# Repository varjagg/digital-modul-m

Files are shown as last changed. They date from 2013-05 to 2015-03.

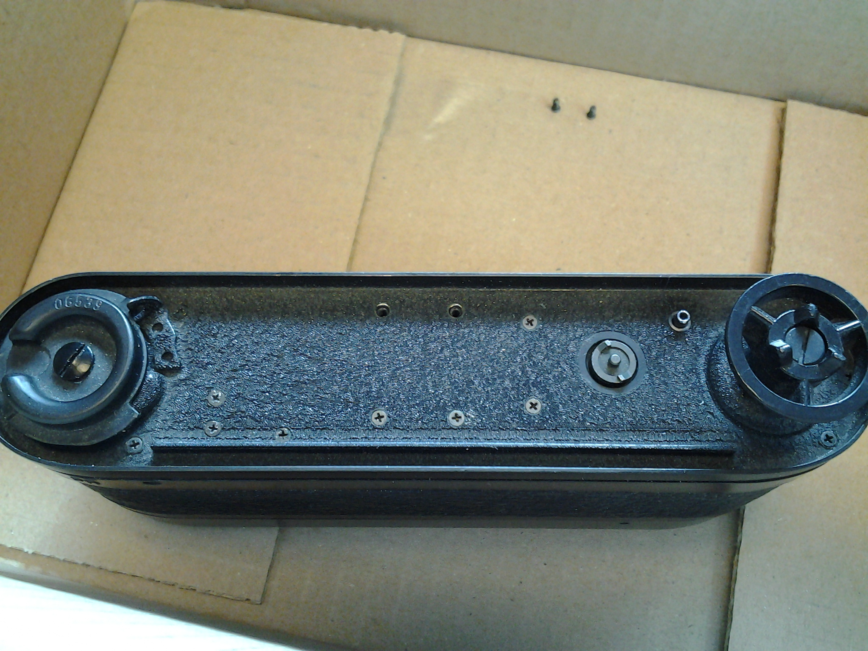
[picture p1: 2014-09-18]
images/assy/2013-04-25 13.17.37.jpg

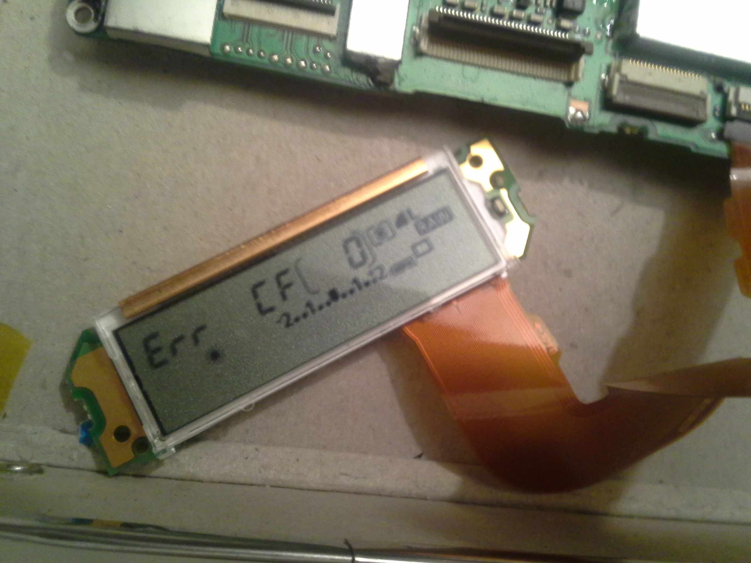
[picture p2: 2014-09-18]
images/assy/2014-04-14 23.03.26.jpg

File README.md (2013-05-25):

Digital Modul M
===============

An Arduino Pro Mini based controller for Canon EOS 350D covnerted into digital back.

Handles shutter release and ISO selection sequence via a 5 position rotary switch.

Handles shutter release from Leica via M Sync (flashbulb) terminal and triggers shutter release on the Canon.

Emulates phantom limbs of the Canon (feedback from shutter and mirror position sensors).

Still work in progress!

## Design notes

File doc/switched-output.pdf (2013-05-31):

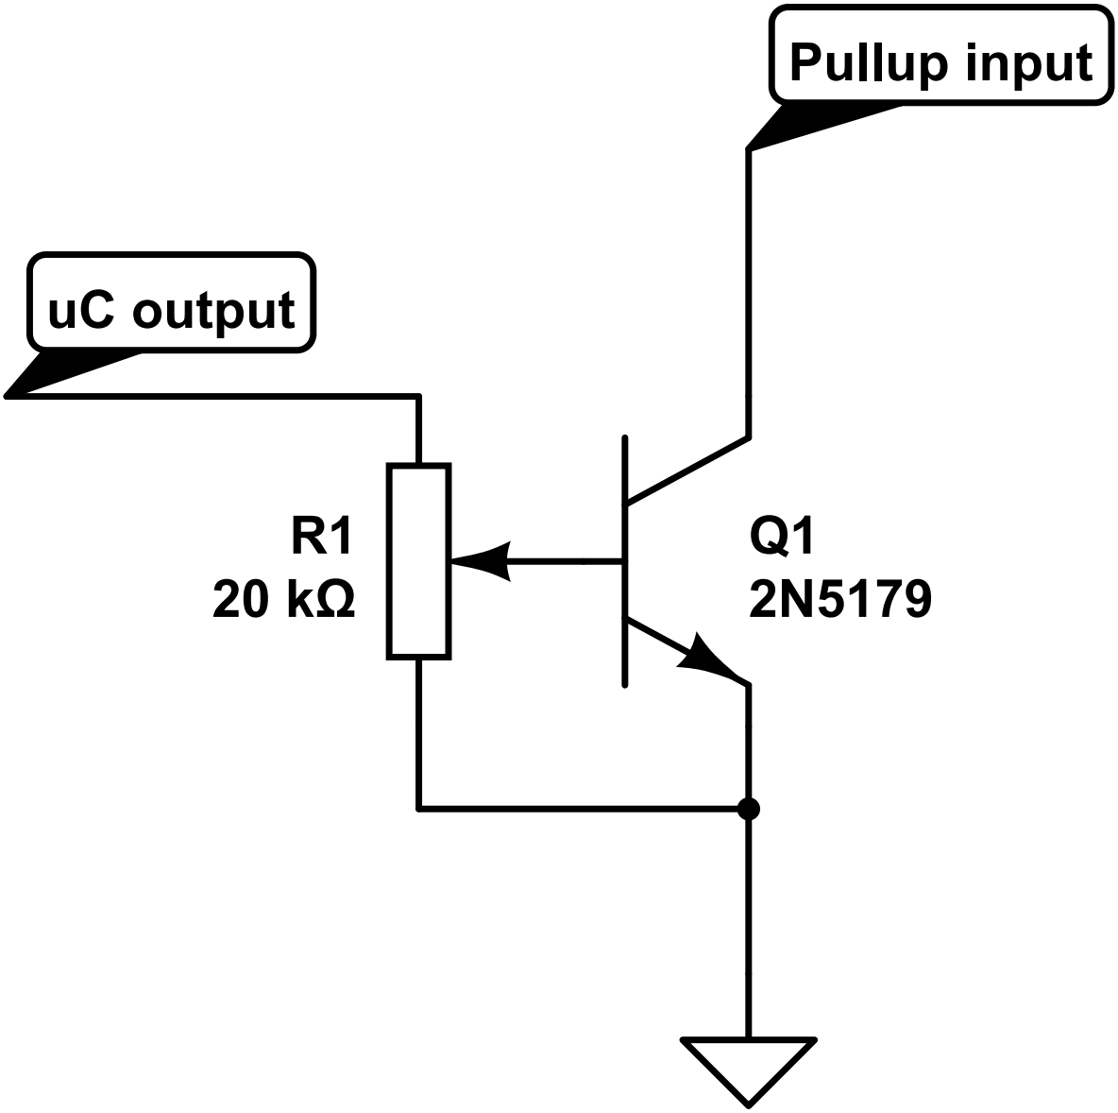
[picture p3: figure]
Pullup input; uC output

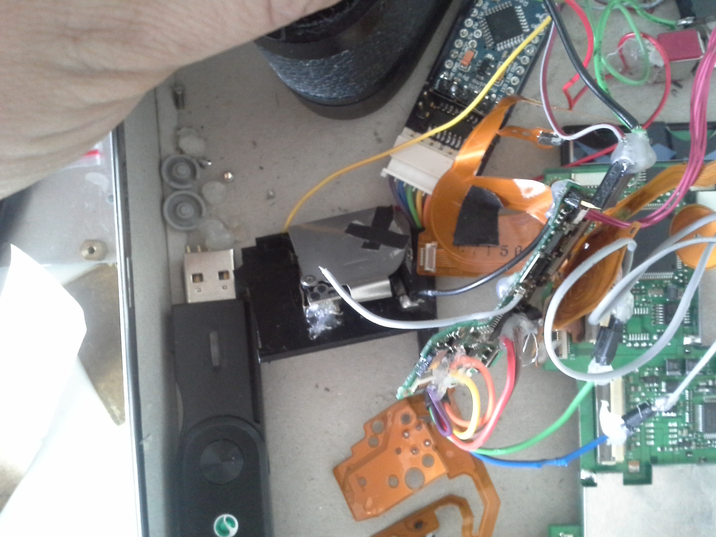
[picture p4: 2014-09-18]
images/assy/2014-08-03 16.27.18.jpg

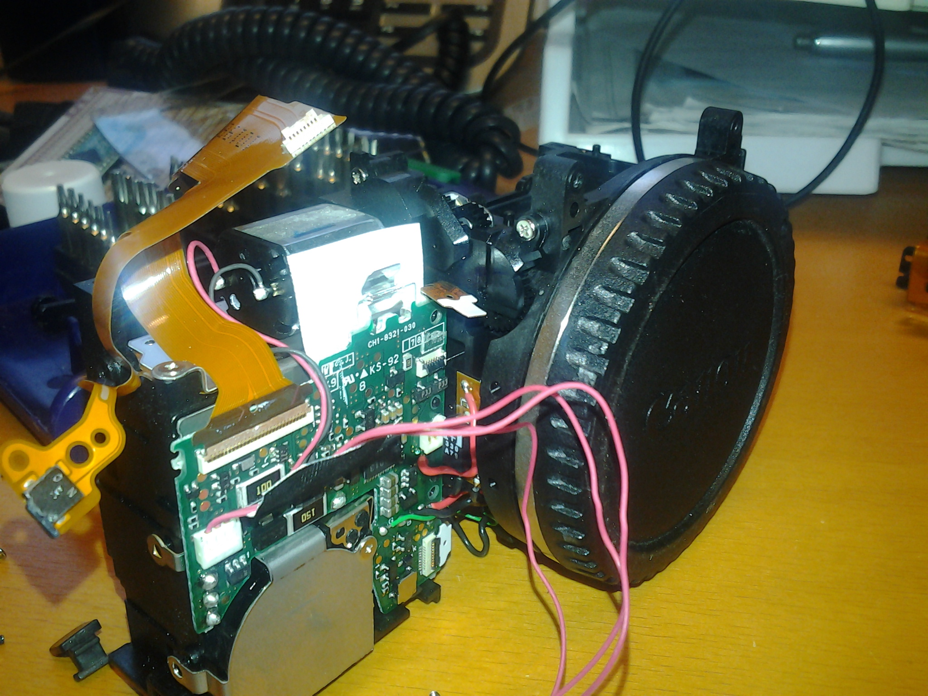
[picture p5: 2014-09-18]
images/assy/2013-05-06 18.22.18.jpg

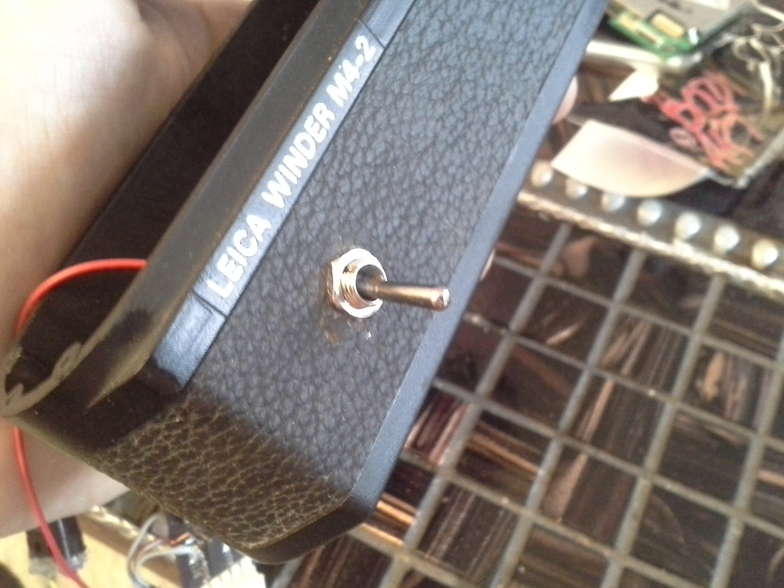
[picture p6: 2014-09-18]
images/assy/2014-08-03 17.57.18.jpg

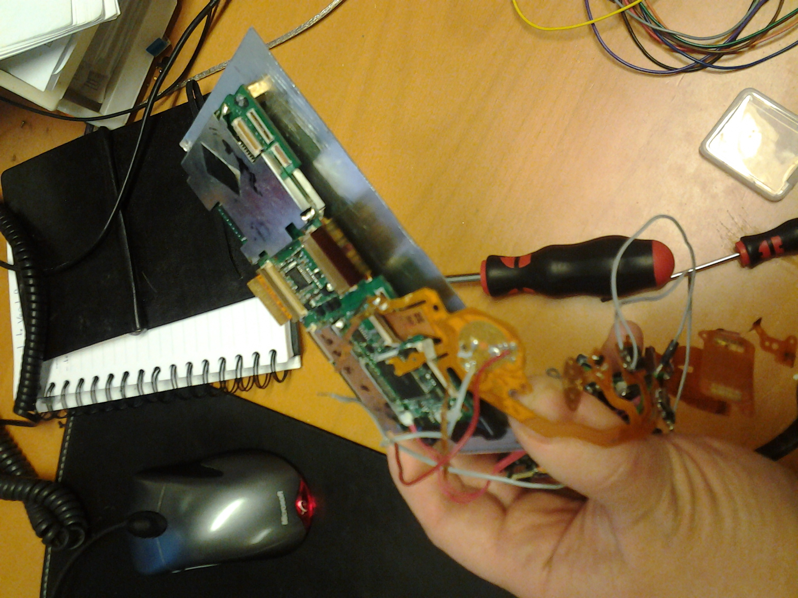
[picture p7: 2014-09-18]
images/assy/2013-12-19 19.09.03.jpg

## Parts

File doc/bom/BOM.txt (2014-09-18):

Bill Of Materials

1. Canon 350d/Rebel XTi camera body         1pcs
2. ULN2003A                                 2pcs
3. Arduino Mini Pro 3.3V                    1pcs
4. PC Sync Cable                            1pcs
5. Omron G5V-1 Relay                        1pcs
6. Sheet Steel, 0.5mm                       1pcs
7. Leica Winder                             1pcs
8. Sugru, 8g Black                          1pk
9. Leica Camera Removable Back              1pcs

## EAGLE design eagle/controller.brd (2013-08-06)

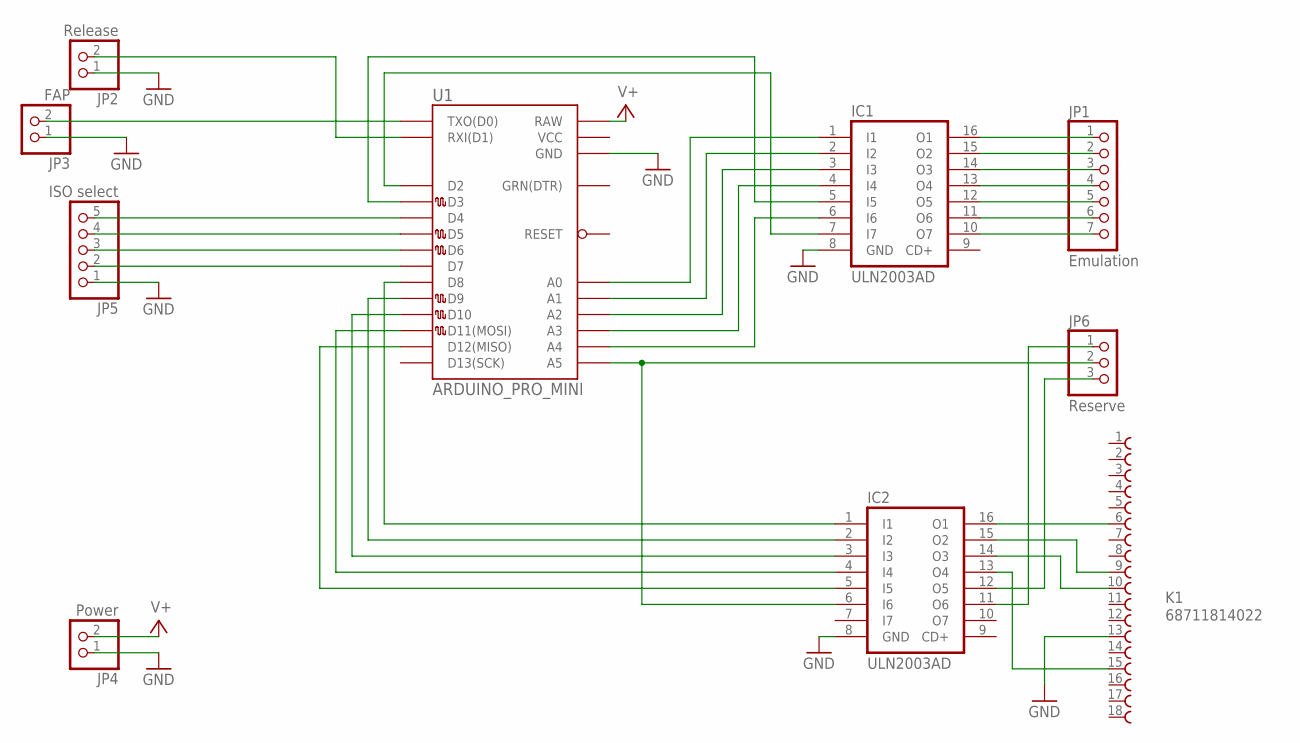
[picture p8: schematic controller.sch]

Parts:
IC1, IC2: ULN2003AD; SO16
JP1: Emulation; 1X07/90
JP2: Release; 1X02
JP3: FAP; 1X02
JP4: Power; 1X02
JP5: ISO select; 1X05/90
JP6: Reserve; 1X03
K1: 68711814022
U1: ARDUINO_PRO_MINI

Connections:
GND: IC1.8 (GND), IC2.8 (GND), JP2.1, JP3.1, JP4.1, JP5.1, K1.13, U1.GND1 (GND)
unnamed: IC1.1 (I1), U1.A0
unnamed: IC1.2 (I2), U1.A1
unnamed: IC1.3 (I3), U1.A2
unnamed: IC1.4 (I4), U1.A3
unnamed: IC1.5 (I5), U1.D3
unnamed: IC1.6 (I6), U1.A4
unnamed: IC1.7 (I7), U1.D2
unnamed: IC2.1 (I1), U1.D8
unnamed: IC2.2 (I2), U1.D9
unnamed: IC2.3 (I3), U1.D10
unnamed: IC2.4 (I4), U1.D11 (D11(MOSI))
unnamed: IC2.5 (I5), U1.D12 (D12(MISO))
unnamed: JP5.5, U1.D4
unnamed: JP5.4, U1.D5
unnamed: JP5.3, U1.D6
unnamed: JP5.2, U1.D7
unnamed: JP3.2, U1.TXO (TXO(D0))
unnamed: JP2.2, U1.RXI (RXI(D1))
unnamed: IC2.6 (I6), JP6.2, U1.A5
unnamed: IC1.16 (O1), JP1.1
unnamed: IC1.15 (O2), JP1.2
unnamed: IC1.14 (O3), JP1.3
unnamed: IC1.13 (O4), JP1.4
unnamed: IC1.12 (O5), JP1.5
unnamed: IC1.11 (O6), JP1.6
unnamed: IC1.10 (O7), JP1.7
unnamed: IC2.11 (O6), JP6.1
unnamed: IC2.16 (O1), K1.6
unnamed: IC2.15 (O2), K1.9
unnamed: IC2.14 (O3), K1.10
unnamed: IC2.13 (O4), K1.15
unnamed: IC2.12 (O5), JP6.3
V+: JP4.2, U1.RAW

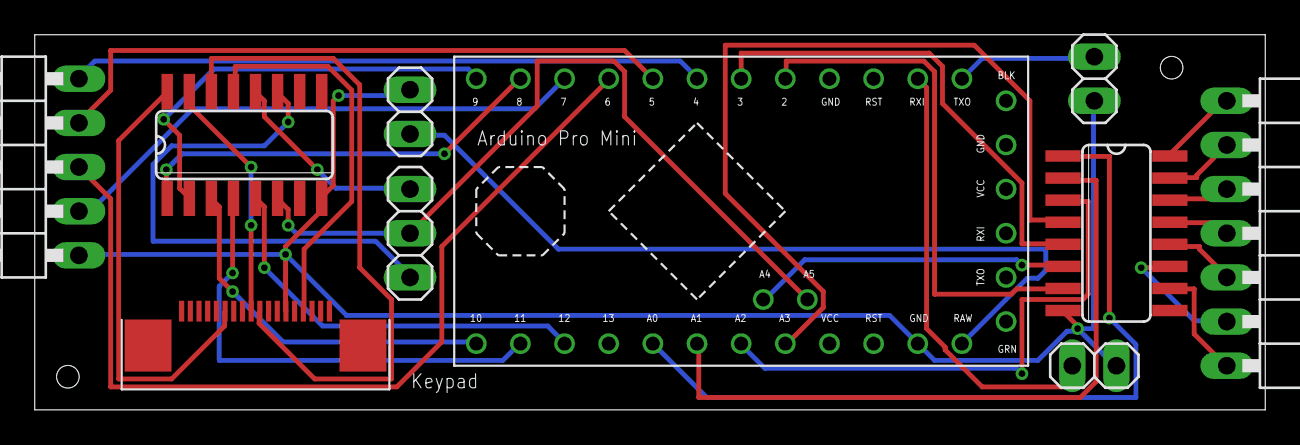
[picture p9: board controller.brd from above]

Board: 2 copper layers, 70.8 x 21.6 mm, 10 parts (0 on the bottom side), 34 nets.

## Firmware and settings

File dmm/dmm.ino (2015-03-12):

// Arduino Pro Mini code to control DIGITAL MODUL M:
// a custom digital back for film Leica M bodies based on Canon EOS 350D
#include <Bounce.h>
#include <EEPROM.h>

// we use a 4 position selector knob, mapped to 4 inputs, to select camera ISO
#define ISO_100  0
#define ISO_200  1
#define ISO_400  2
#define ISO_800  3

// TODO: playback and zoom-in 100% while this button is held
#define IN_FAP 0

#define IN_SHUTTER 1
#define BTN_SHUTTER 3
#define BTN_PRERELEASE A4
#define SW_MYSTERY 2

// we drive the amputated 350D buttons from output pins
#define BTN_ISO 8
#define BTN_UP  8
#define BTN_DN  10
#define BTN_SET 9
#define BTN_PLAY 11
#define BTN_ZOOM_IN 12
#define SW_CANON_PWR 12

// we simulate the shutter curtain and mirror position sensors for the Canon
#define SW_SHUTTER_CURTAIN1 A0
#define SW_SHUTTER_CURTAIN2 A1
#define SW_MIRROR_UP A2
#define SW_MIRROR_DOWN A3

#define SW_POWER A5

#define ISO_ADDR 0

#define out_on(pin_no) digitalWrite(pin_no, HIGH);
#define out_off(pin_no) digitalWrite(pin_no, LOW);

int isopos;

int buttons[4]={
  7, 6, 5, 4};
//Bounce *buttons_deb[4];

//Bounce button_fap = Bounce(IN_FAP, 15);

// blink the led once
void blink() {
  digitalWrite(13, HIGH);
  delay(100);
  digitalWrite(13, LOW);
  delay(100);
}

// simulate a keypress action
void click(int pin) {
  digitalWrite(pin, HIGH);
  delay(20);
  digitalWrite(pin, LOW);
  delay(20);
}

//zoom in the image to 100% center
void pixelpeep() {
  click(BTN_PLAY);
  click(BTN_ZOOM_IN);
  click(BTN_ZOOM_IN);
  click(BTN_ZOOM_IN);
  click(BTN_ZOOM_IN);
  click(BTN_ZOOM_IN);
  click(BTN_ZOOM_IN);
  click(BTN_ZOOM_IN);
  click(BTN_ZOOM_IN);
}

int getRotaryPos() {
  int i, pos = 0
  ;
  for(i = 7; i > 3; i--) {
    if(digitalRead(i) == LOW)
      pos = i - 3;
  }
  if (i < 0)
    i = 4;
  
  return pos;
}

// ISO selection button sequence
void iso_seq(int pos) {
  int dist, dir;
  click(BTN_ISO);

  dist = pos - isopos;
  dir = (dist >= 0 ? 1 : -1);
  // drive the cursor to required position
  for(; pos != isopos; isopos += dir) {
    click(dir > 0 ? BTN_DN : BTN_UP);
  }
  click(BTN_SET);
  
  EEPROM.write(ISO_ADDR, isopos);
}

// camera firing sequence
void shoot() {

  out_on(BTN_SHUTTER);
  delay(8); // minimum trigger time
  out_off(SW_MIRROR_DOWN);
  delay(24);
  //Set mirror up and fire the 1st curtain
  out_on(SW_MIRROR_UP);
  out_off(BTN_SHUTTER);
  delay(33);
  out_off(SW_SHUTTER_CURTAIN1);
  out_off(BTN_PRERELEASE);
  digitalWrite(13, HIGH); //LED on
  delay(495); // Canon's shutter is set to 1/2 sec
  out_off(SW_SHUTTER_CURTAIN2);
  delay(35);
  out_off(SW_MIRROR_UP);
  delay(33);
  out_on(SW_SHUTTER_CURTAIN1);
  delay(5);
  out_on(SW_SHUTTER_CURTAIN2);
  delay(28);
  out_on(SW_MYSTERY);
  delay(40);
  out_off(SW_MYSTERY);
  delay(1);
  out_on(SW_MIRROR_DOWN);

  digitalWrite(13, LOW); //LED off

}

void setup() {
  int i;
  pinMode(13, OUTPUT);
  digitalWrite(13, LOW);

  EEPROM.write(ISO_ADDR, 0);

  isopos = EEPROM.read(ISO_ADDR);

  // shutter release button
  pinMode(IN_SHUTTER, INPUT_PULLUP);

  // camera circuit power
  out_off(SW_CANON_PWR);
  pinMode(SW_CANON_PWR, OUTPUT);
  out_off(SW_POWER);
  pinMode(SW_POWER, OUTPUT);

  // fap button
  pinMode(IN_FAP, INPUT_PULLUP);
  
  // set up the inputs from ISO knob
  for(i = 0; i < 4; i++) {
    pinMode(buttons[i], INPUT_PULLUP);
    //buttons_deb[i] = new Bounce(buttons[i], 32);
  }

  out_off(BTN_PRERELEASE);
  out_off(BTN_SHUTTER);
  pinMode(BTN_SHUTTER, OUTPUT);
  pinMode(BTN_PRERELEASE, OUTPUT);
  pinMode(SW_MYSTERY, OUTPUT);
  pinMode(BTN_ISO, OUTPUT);
  pinMode(BTN_UP, OUTPUT);
  pinMode(BTN_DN, OUTPUT);
  pinMode(BTN_SET, OUTPUT);

  out_on(SW_SHUTTER_CURTAIN1);
  out_on(SW_SHUTTER_CURTAIN2);
  pinMode(SW_SHUTTER_CURTAIN1, OUTPUT);
  pinMode(SW_SHUTTER_CURTAIN2, OUTPUT);
  out_on(SW_MIRROR_DOWN);
  out_off(SW_MIRROR_UP);
  pinMode(SW_MIRROR_UP, OUTPUT);
  pinMode(SW_MIRROR_DOWN, OUTPUT);

  // delay to let the camera warm up
  out_on(SW_CANON_PWR);
  out_on(SW_POWER);
  delay(250);
  out_off(SW_MYSTERY);

  delay(2000); 
  out_on(BTN_PRERELEASE);
}

void loop() {
  int new_iso;
  
  // fire the shutter if necessary
  if(digitalRead(IN_SHUTTER) == LOW) {
    shoot();
    delay(500);
    out_on(BTN_PRERELEASE);

  }

  new_iso = getRotaryPos();
  if ( new_iso != isopos )
    if( new_iso == 4 && isopos != 3 )
      delay(100);
    else
       iso_seq(new_iso);
       
}

  

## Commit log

2013-04-26 fixing the iso selection
    [dmm.ino]
2013-04-26 iso button is the up button
2013-05-08 LED trace
2013-05-22 moved implementation to smaller arduino mini pro 3.3v
2013-05-22 fixed the pin assignments
    [dmm.ino]
2013-05-22 fixed the pin assignments again
    [dmm.ino]
2013-05-24 Fixes ISO selector bug
    [dmm.ino]
2013-05-28 added control pcb shot
2013-05-31 added switched output diagram
2013-06-14 First working version
    Capture without physical shutter and mirror assembly now works, but stalls with Error99 on 4th shot.
    [dmm.ino]
2013-07-02 pcb schematics import
    [controller.sch]
2013-07-02 added BOM
2013-07-11 a working version with pre-release control - still fails at 4th shot
    [dmm.ino]
2013-07-11 a version with direct connection without switches
2013-07-12 direct connection version, fixes ERROR99 issue and performs complete shutter and mirror emulation
    [dmm.ino]
2013-07-15 schematics added
    [controller.brd, controller.sch]
2013-07-15 routed the board, updated bom
    [controller.brd, controller.sch]
2013-07-16 changed pin assignments
2013-07-17 removed a glitch in initialization sequence
    [dmm.ino]
2013-07-17 changes to iso switch decoding
2013-07-19 updated schematics
    [DRILEGEND.CFG]
2013-07-22 traced the board
    [controller.brd]
2013-08-06 production board REVA
    [controller.brd, controller.sch]
2013-08-30 inverting signals for ULN2003
    [dmm.ino]
2013-09-20 new iso switching code
2014-05-05 Update dmm.ino
    Added Canon PCBs power control.
2014-07-12 Trimmed the lag timings to shortest possible
    Also fixed the ERROR99 when starting up with sync cable plugged in.
    [dmm.ino]

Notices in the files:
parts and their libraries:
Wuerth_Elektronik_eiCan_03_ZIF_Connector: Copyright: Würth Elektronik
